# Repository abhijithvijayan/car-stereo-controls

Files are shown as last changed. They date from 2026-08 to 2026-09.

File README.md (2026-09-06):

# wireless-steering-wheel-controls

> ⚠️ Work in progress

Wireless steering-wheel audio controls for a car head unit.

The steering-wheel buttons can't be wired through to the dash, and the head unit
only accepts commands over its wired SWC (steering-wheel-control) resistor input.
So the link is split in two over BLE:

```
[steering wheel]                         [behind dash, car-powered]
 buttons → XIAO nRF52840  ──BLE──▶  ESP32-C3  ──resistor codes──▶  head unit SWC input
 (coin-cell powered)                (always on, scans)
```

## Subprojects

| Dir | Board | Role |
|-----|---|---|
| [`transmitter/`](transmitter/) | Seeed XIAO nRF52840 | On the wheel, battery powered. Reads the button cluster and broadcasts presses over connectionless BLE advertising. |
| [`receiver/`](receiver/) | ESP32-C3 | Behind the dash, always powered. Scans for the broadcasts and drives the head unit's SWC input. |

Each subproject is a self-contained PlatformIO project — open the subdirectory
(not this root) in your IDE, or build from inside it:

```bash
cd transmitter && pio run    # or: pio run -t upload
cd receiver     && pio run
```

## How it works

Signal path: button resistance → ADC voltage → BLE packet → mux channel
selection → resistance on the SWC wire → voltage read by the head unit.

### Transmitter (wheel side)

The wheel's 9 buttons form a resistor ladder on a single analog wire: each
button connects a different cumulative resistance (360 Ω–16.46 kΩ) to ground.
The XIAO idles in sleep (~20 µA) and wakes on a button press via a GPIO PORT
event. It then drives the ladder through a 5.1 k series resistor, samples the
node with the ADC (median of 3), and classifies the button by comparing the
resistance against a threshold table.

Button events are broadcast as connectionless BLE advertisements (no pairing,
no connection) carrying 7 bytes of manufacturer data:

```
[FF FF] [42]  [01]    [button] [event]              [seq]
company magic version 0-8      PRESS/HOLD/RELEASE   +1 per event
```

Repeatable buttons (VOL±/SRC±) re-send HOLD every 200 ms while held. Every
frame is re-broadcast unchanged until the next event, which serves as a
heartbeat. The chip returns to sleep 1 s after release.

### Receiver (dash side)

An ESP32-C3 scans passively at 100% duty cycle. The BLE callback filters on
company + magic + version, deduplicates by sequence number (each frame arrives
many times), and writes the newest event into a single-slot mailbox
(overwrite, not a FIFO: queued stale PRESS/RELEASE events would no longer
describe the current button state). A local rotary encoder (volume knob) is
decoded by a quadrature state machine; each detent enqueues one tap into a
ring buffer.

Both inputs are consumed by a single output state machine — the only code
that drives the output pins. A held wheel button is mirrored: its code is
asserted while the button is held, re-asserted only when the button changes,
and released on RELEASE or after 500 ms without a heartbeat (failsafe against
a dead transmitter). Encoder detents are counted and emitted as 50 ms press
pulses with 50 ms spacing between pulses.

### Output stage → head unit

Asserting a button: two 74HC4051 analog multiplexers (shared S0–S2 select
lines; per-mux active-low enables with 10 k pull-ups so both muxes are off
until the firmware initializes) connect one of nine fixed resistors between a
head-unit SWC wire and ground. Each mux common reaches its SWC wire through a
photoMOS solid-state relay (see [power-fail isolation](#power-fail-isolation)
below). Electrically this is identical to a wired OEM button press.

The head unit holds each SWC input at 3.335 V through an internal ~650 Ω
pull-up and reads the divider voltage produced by the pressed button's
resistance (V = 3.335 · (R + R_on) / (R + R_on + 650), with mux
R_on ≈ 130 Ω). In learning mode it stores one voltage per button and later
matches live readings within roughly ±50 mV.

Installed codes:

| Ref | Button | Mux/channel | Resistor | Wire voltage |
|-----|---|---|---|---|
| R1  | VOL_UP | M1 / Y0 | 100 Ω | 0.87 V |
| R2  | SRC_PUSH  | M1 / Y1 | 220 Ω | 1.16 V |
| R3  | SRC_UP | M1 / Y2 | 330 Ω | 1.38 V |
| R4  | SRC_DOWN  | M1 / Y3 | 470 Ω | 1.60 V |
| R7  | CALL_END  | M2 / Y2 | 680 Ω | 1.85 V |
| R8  | VOICE | M2 / Y1 | 1 k | 2.11 V |
| R5  | VOL_DOWN  | M1 / Y4 | 2 k | 2.55 V |
| R9  | ANSWER | M2 / Y0 | 3.3 k | 2.80 V |
| R6  | MUTE | M1 / Y5 | 6.8 k | 3.05 V |
| — | idle | — | open | 3.335 V |

(M1 common → SSR → SWC wire 1, M2 common → SSR → SWC wire 2, shared ground.
Support parts: R10/R11 = 10 k pull-ups on the mux enables, C1/C2 = 100 nF
decoupling at each mux VCC, U3/U5 = AQY212EH photoMOS relays with
R12/R13 = 680 Ω LED resistors.)

The nine values are chosen for voltage spacing on the head unit's divider —
minimum ~215 mV between any two codes on the combined axis (placed on the
rarely-used SRC pair), ≥ 245 mV around the volume/mute/call buttons, and the
set is collision-free even if the head unit compares both wires against one
learned list. They are unrelated to the wheel's own ladder values: a
resistance code is only meaningful relative to the pull-up that reads it, and
the two sides have different pull-ups (5.1 k vs ~650 Ω) — the wheel's
16.46 kΩ top value would compress to unusably small voltage steps on a 650 Ω
divider.

### Power-fail isolation

The receiver is powered from the head unit's own USB port, and the head unit
can be on while the receiver is dead — during engine cranking (the head unit
sheds its USB load for a few seconds) or with the cable unplugged. An
unpowered 74HC4051 is not an open circuit: like most CMOS parts it has ESD
protection diodes from every signal pin to VCC, so the head unit's 650 Ω
pull-up back-feeds through the mux common into the dead 3.3 V rail. The SWC
wires sag from 3.335 V to ~2.2 V — right at a learned code's window, with
others swept through on the way — so a dead receiver used to press phantom
buttons. No firmware can help, because none is running.

As defense in depth, the button assignment accounts for this: the ~2.1 V slot
nearest the back-feed voltage belongs to VOICE (a phantom there only pokes the
voice assistant), while the phone-critical ANSWER sits at 2.80 V, far from
every measured fault voltage.

The fix is a normally-open photoMOS relay (Panasonic AQY212EH) in series
between each mux common and its SWC wire. The relay's input side is an
internal infrared LED fed from the raw USB 5 V rail through 680 Ω (~5.5 mA,
inside the datasheet's recommended 5–10 mA band; still ≥4 mA above the 3 mA
guaranteed trigger at the worst-case corner of USB's 4.4 V floor, max LED Vf,
and resistor tolerance). The only coupling to the output MOSFETs is light:
when USB power dies the LED goes dark and the outputs become a genuinely open
circuit, so the wires float at the 3.335 V idle exactly as if nothing were
connected. The LED resistors tap the 5 V node ahead of the module's regulator
and bulk capacitance so the relays open before the 3.3 V rail can sag into
the back-feed region.

Cost of the extra series element: ~0.85 Ω on-resistance, which shifts the
most sensitive code (VOL_UP) by ~3 mV and the gaps between codes by even
less — re-running the head unit's learning mode after installation absorbs
it entirely.

## Third-party code & assets

Everything not listed below is original work under [MIT](LICENCE).

### Code

- `receiver/src/rotary_encoder.{h,cpp}` — quadrature state tables derived from
  [Ben Buxton's rotary library](https://github.com/buxtronix/arduino/tree/master/libraries/Rotary),
  Copyright 2011 Ben Buxton, **GPL v3**. These two files remain under GPL v3 (it
  cannot be relicensed to MIT); fine for private/personal use, but they carry
  GPL terms if this repo is ever distributed.

### Hardware / CAD

- `circuit/custom/Seeed_Studio_XIAO_Series.kicad_sym` and
  `circuit/custom/XIAO-nRF52840-DIP.kicad_mod` — KiCad schematic symbol and
  footprint from Seeed Studio's official
  [XIAO KiCad libraries](https://wiki.seeedstudio.com/XIAO_BLE/#seeed-studio-xiao-nrf52840)
  ([symbols](https://files.seeedstudio.com/wiki/XIAO-KiCad-Library/XIAO_Series_SCH_Symbols.zip),
  [footprints](https://files.seeedstudio.com/wiki/XIAO-KiCad-Library/New_XIAO_Series_Footprints.zip)),
  © Seeed Studio, [CC BY-SA 4.0](https://wiki.seeedstudio.com/License/)
  (Seeed wiki resources license). The footprint has local modifications;
  as CC BY-SA derivatives, these two files remain CC BY-SA 4.0.

- `circuit/custom/ESP32-C3_SUPERMINI_TH.kicad_sym`,
  `circuit/custom/MODULE_ESP32-C3_SUPERMINI_TH.kicad_mod`, and
  `circuit/custom/ESP32-C3_SUPERMINI_TH.step` — symbol, footprint, and 3D model
  from [SnapMagic Search (SnapEDA)](https://www.snapeda.com/parts/ESP32-C3%20SuperMini_TH/Espressif%20Systems/view-part/),
  [CC BY-SA 4.0 with Design Exception 1.0](https://support.snapeda.com/en/articles/2957814-what-is-the-license-for-symbols-and-footprints)
  (the exception lets designs and boards built with these files be licensed
  freely; the files themselves remain CC BY-SA with attribution).

- `circuit/custom/XIAO-nRF52840 v15.step` — 3D board model from the GrabCAD
  Community Library:
  [Seeed Studio XIAO nRF52840 (Sense)](https://grabcad.com/library/seeed-studio-xiao-nrf52840-sense-1).
  ⚠️ GrabCAD community models are licensed for **private use**; public
  redistribution requires the uploader's permission.

- `3d models/battery_case.FCStd` and `3d models/Battery Enclosure - cr2450.stl`
  — CR2450 battery holder: FreeCAD project created to modify, and the modified
  STL exported from, the
  [CRxxxx battery holder generator](https://cults3d.com/en/3d-model/tool/crxxxx-battery-holder-generator)
  output by **shusy** on Cults3D, **CC BY-NC** — both files remain CC BY-NC.
  `3d models/transmitter_case.FCStd` is original work but embeds the modified
  holder, so it is not usable commercially as a whole.

### Tools

Designed with [KiCad](https://www.kicad.org/) (PCB) and
[FreeCAD](https://www.freecad.org/) (enclosure); the PCB was brought into the
FreeCAD enclosure project with
[kicadStepUp](https://github.com/easyw/kicadStepUpMod/) (easyw, AGPL-3.0).
Firmware built with [PlatformIO](https://platformio.org/). Tool licenses do
not apply to this repo's content.

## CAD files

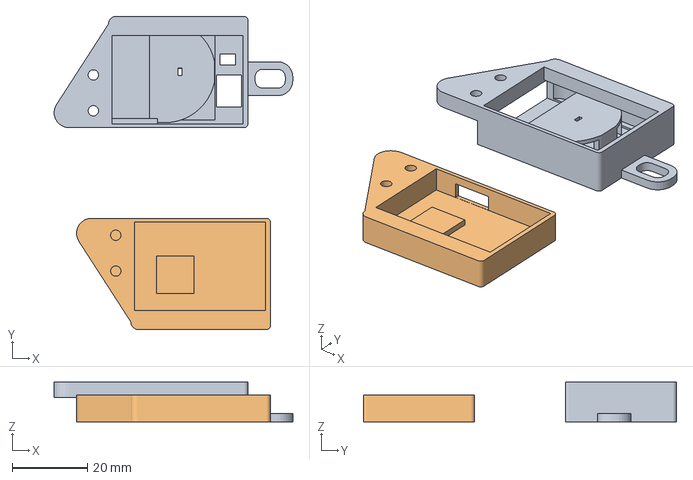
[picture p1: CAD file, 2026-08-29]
3d models/Transmitter Case - Slicer File.3mf
63.3 x 83.0 x 10.6 mm
Transmitter Case.stl x 2

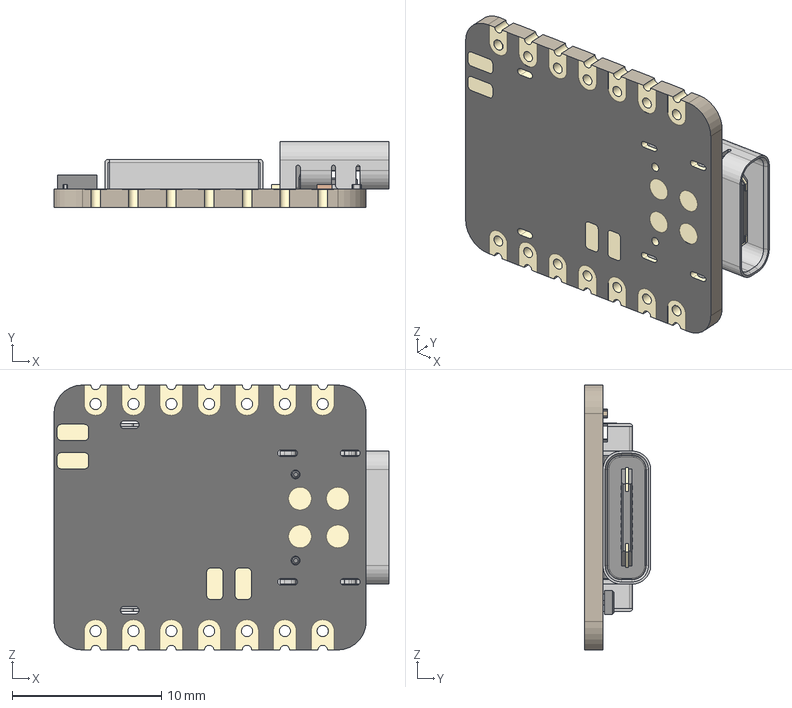
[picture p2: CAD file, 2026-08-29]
circuit/custom/XIAO-nRF52840 v15.step
22.5 x 4.46 x 17.8 mm
BOSS-EXTRUDE14_8_
BOSS-EXTRUDE7_4_
BOSS-EXTRUDE7_3_
BOSS-EXTRUDE14_4_
BOSS-EXTRUDE14_2_
BOSS-EXTRUDE14_11_
BOSS-EXTRUDE7_7_
BOSS-EXTRUDE14_9_
BOSS-EXTRUDE14_3_
BOSS-EXTRUDE14_7_
MIRROR2
BOSS-EXTRUDE14_5_
BOSS-EXTRUDE14_12_
BOSS-EXTRUDE7_8_
BOSS-EXTRUDE7_1_
BOSS-EXTRUDE14_10_
BOSS-EXTRUDE7_9_
BOSS-EXTRUDE14_6_
BOSS-EXTRUDE14_1_
BOSS-EXTRUDE7_6_
BOSS-EXTRUDE7_2_
CUT-EXTRUDE5
BOSS-EXTRUDE7_5_
Shield
Pins
CAP x 2
ANT1
Silkscreen
CAP 3
LED
USR
2 v1

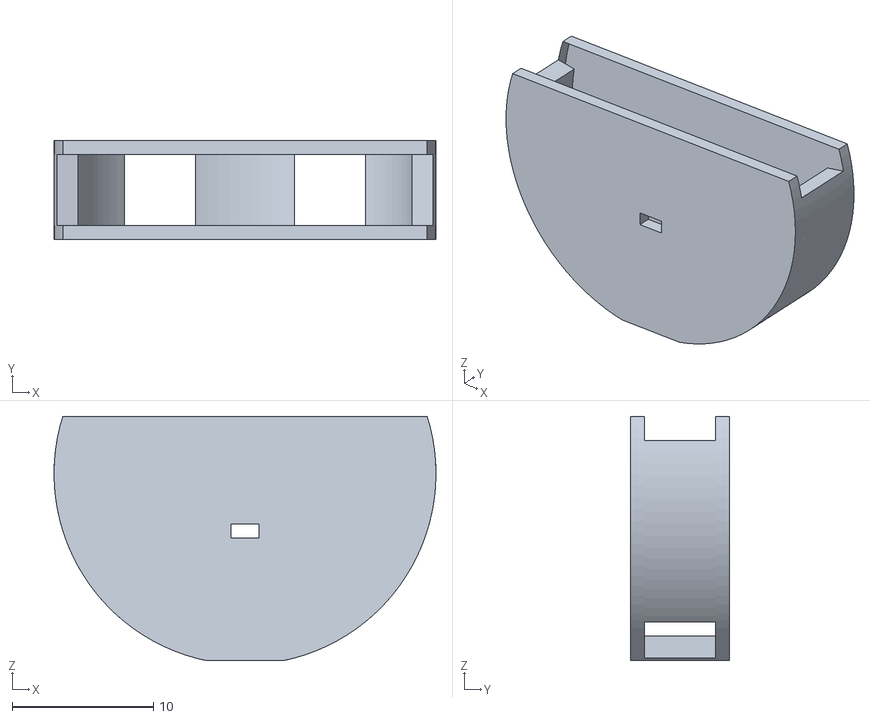
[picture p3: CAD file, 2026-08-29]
3d models/Battery Enclosure - cr2450.stl
27.0 x 7.00 x 17.3

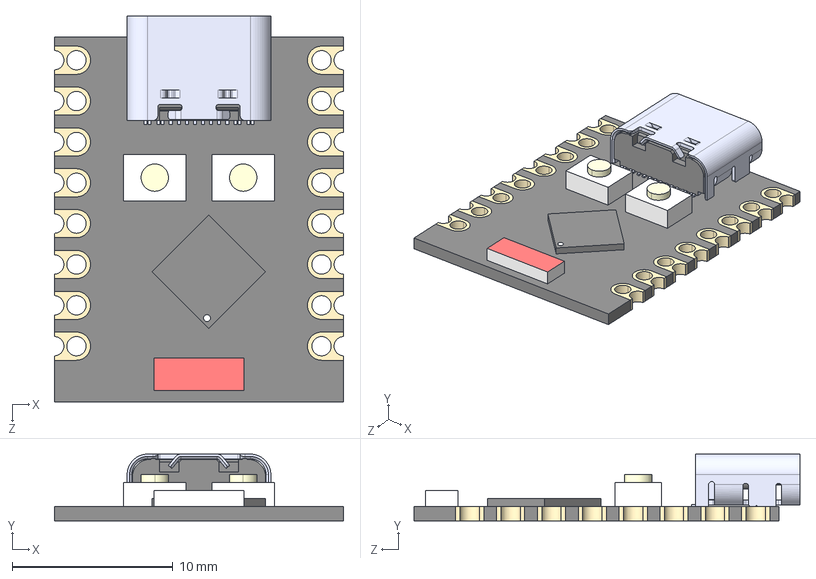
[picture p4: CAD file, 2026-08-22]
circuit/custom/ESP32-C3_SUPERMINI_TH.step
18.0 x 4.16 x 24.0 mm
Board c3mini
USB C
components (other)^ESP32-C3 SuperMini

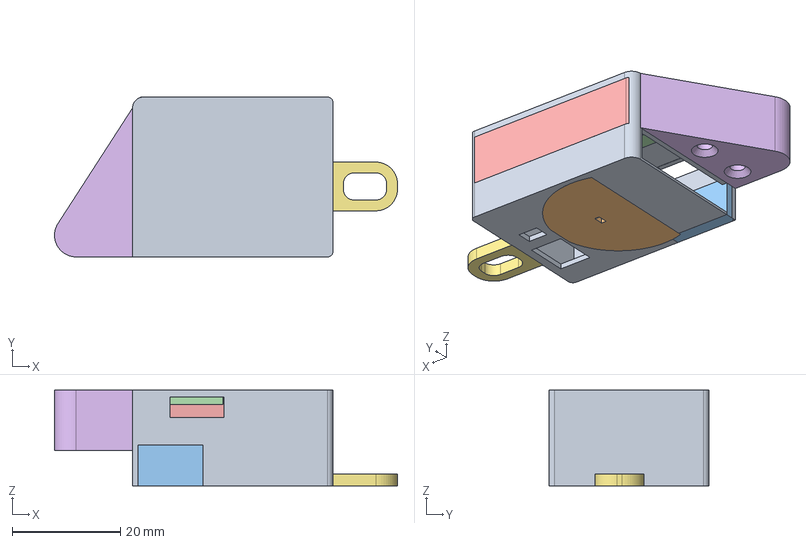
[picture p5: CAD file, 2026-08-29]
3d models/transmitter_case.FCStd
63.3 x 29.5 x 17.7 mm
Case
Battery Case
Lift 1
Support Top
Backsupport
Top support
Screw Clip

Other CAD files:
3d models/battery_case.FCStd
3d models/Transmitter Case.stl

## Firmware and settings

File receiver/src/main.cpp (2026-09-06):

/*
 *  Dash unit — ESP32-C3 BLE scanner + SWC output stage.
 */

// Framework headers aren't -Wconversion clean; silence their warnings so the flag
// (build_src_flags in platformio.ini) only polices our own code below.
#pragma GCC diagnostic push                         // save current warning settings
#pragma GCC diagnostic ignored "-Wconversion"       // turn THIS warning off
#pragma GCC diagnostic ignored "-Wsign-conversion"  // turn THIS warning off
#include <Arduino.h>                                // code compiled here uses the relaxed setting
#include <NimBLEDevice.h>
#pragma GCC diagnostic pop                          // restore what was saved at step 1

#include <swc_protocol.h>
#include <rotary_encoder.h>

using namespace swc;

// cooperative yield per loop pass (keeps BLE/idle/watchdog alive)
constexpr uint32_t LOOP_YIELD_MS = 5;

constexpr uint32_t HEARTBEAT_TIMEOUT_MS = 500;

constexpr uint8_t PIN_MUX_S0 = 0;
constexpr uint8_t PIN_MUX_S1 = 1;
constexpr uint8_t PIN_MUX_S2 = 3;
constexpr uint8_t PIN_MUX_1_ENABLE = 4;
constexpr uint8_t PIN_MUX_2_ENABLE = 5;

constexpr uint8_t PIN_ENCODER_A = 9;
constexpr uint8_t PIN_ENCODER_B = 8;
constexpr uint8_t PIN_ENCODER_PUSH = 10;

// push contact must be edge-free this long before a press-down edge counts
constexpr uint32_t PUSH_QUIET_MS = 30;

RotaryEncoder encoder(PIN_ENCODER_A, PIN_ENCODER_B, EncoderStepMode::FULL_STEP);

volatile uint8_t pendingWheelButton = BUTTON_NONE;
volatile uint8_t pendingWheelEvent = RELEASE;
volatile bool hasPendingWheelEvent = false;
volatile uint32_t lastWheelHeardAt = 0; // heartbeat for the timeout failsafe

enum OutputState : uint8_t {
    OUTPUT_IDLE,
    OUTPUT_ACTIVE
};

OutputState outputState = OUTPUT_IDLE;
uint8_t currentActiveButton = BUTTON_NONE;

class BLEScanCallback : public NimBLEScanCallbacks {
    public: void onResult(const NimBLEAdvertisedDevice *device) override {
        const std::string manufacturerData = device->getManufacturerData();
        if (manufacturerData.length() != PACKET_LENGTH) {
            return;
        }

        const auto *packet = reinterpret_cast<const uint8_t *>(manufacturerData.data());
        if (packet[0] != COMPANY_ID_LO || packet[1] != COMPANY_ID_HI || packet[2] != MAGIC || packet[3] != VERSION) {
            return;
        }

        const uint32_t now = millis();
        const uint32_t sinceLast = now - lastWheelHeardAt;
        lastWheelHeardAt = now;

        const uint8_t button = packet[PacketIndex::BUTTON_DATA];
        const uint8_t event = packet[PacketIndex::EVENT_DATA];
        const uint8_t sequence = packet[PacketIndex::SEQUENCE_NUMBER];

        static bool initialized = false;
        // The wheel re-broadcasts the same frame until the next event; act once per sequence.
        static uint8_t lastSequence = 0;
        const bool isNewSession = !initialized || sinceLast > HEARTBEAT_TIMEOUT_MS;
        if (!isNewSession && sequence == lastSequence) {
            return;
        }

        initialized = true;
        lastSequence = sequence;

        pendingWheelButton = button;
        pendingWheelEvent = event;
        hasPendingWheelEvent = true;

        #ifdef DEBUG_BUILD
            const char *eventName =
                event == PRESS   ? "PRESS"   :
                event == HOLD    ? "HOLD"    :
                event == RELEASE ? "RELEASE" :
                event == FAULT   ? "FAULT"   : "?";
            const uint8_t batteryByte = packet[PacketIndex::BATTERY_LEVEL];
            if (batteryByte == BATTERY_NOT_SAMPLED) {
                Serial.printf("[%s] RSSI %d button=%u event=%s seq=%u batt=n/a\n", device->getAddress().toString().c_str(), device->getRSSI(), button, eventName, sequence);
            } else {
                Serial.printf("[%s] RSSI %d button=%u event=%s seq=%u batt=%umV\n", device->getAddress().toString().c_str(), device->getRSSI(), button, eventName, sequence,
                              static_cast<unsigned>(batteryByte) * BATTERY_UNIT_MILLIVOLTS);
            }
        #endif
    }
};

void setAddress(const uint8_t channel) {
    digitalWrite(PIN_MUX_S0, (channel & 0x01u) ? HIGH : LOW);
    digitalWrite(PIN_MUX_S1, (channel & 0x02u) ? HIGH : LOW);
    digitalWrite(PIN_MUX_S2, (channel & 0x04u) ? HIGH : LOW);
}

void releaseCodes() { // Ē active-low → HIGH = off
    digitalWrite(PIN_MUX_1_ENABLE, HIGH);
    digitalWrite(PIN_MUX_2_ENABLE, HIGH);
}

void activateKeyCode(const uint8_t button) {
    const OutputCode &code = OUTPUT_CODES[button];
    releaseCodes();
    setAddress(code.channel);
    digitalWrite(code.mux == MUX_1 ? PIN_MUX_1_ENABLE : PIN_MUX_2_ENABLE, LOW);
}

void setup() {
    // The 74HC4051's enable pin is Ē — active-low (the bar over the E means "true when low")
    // Ē = LOW → mux is on, Ē = HIGH → mux is off
    // pinMode MUST come first: this core discards digitalWrite() on an unconfigured pin,
    // so a preceding write would be a no-op and the pin would come up driving LOW.
    // R10/R11 hold Ē high until here; the µs LOW blip between the two calls is far
    // below what the stereo's SWC sensing can register.
    pinMode(PIN_MUX_1_ENABLE, OUTPUT);
    digitalWrite(PIN_MUX_1_ENABLE, HIGH);

    pinMode(PIN_MUX_2_ENABLE, OUTPUT);
    digitalWrite(PIN_MUX_2_ENABLE, HIGH);

    pinMode(PIN_MUX_S0, OUTPUT);
    digitalWrite(PIN_MUX_S0, LOW);
    pinMode(PIN_MUX_S1, OUTPUT);
    digitalWrite(PIN_MUX_S1, LOW);
    pinMode(PIN_MUX_S2, OUTPUT);
    digitalWrite(PIN_MUX_S2, LOW);

    // the encoder's common pin is wired to GND, so its contacts pull lines down; the internal ~45 k pull-ups give the idle-HIGH level
    encoder.begin();
    pinMode(PIN_ENCODER_PUSH, INPUT_PULLUP);

    #ifdef DEBUG_BUILD
        Serial.begin(115200);
    #endif

    NimBLEDevice::init("");
    NimBLEScan *scan = NimBLEDevice::getScan();
    scan->setScanCallbacks(new BLEScanCallback());
    scan->setActiveScan(false); // We only get advertisements passively
    scan->setInterval(100); // 100ms scan cycle
    scan->setWindow(100); // window == interval -> radio listening 100% of the time
    scan->setDuplicateFilter(false); // deliver EVERY advertisement, even from known devices
    scan->start(0, false); // 0 = scan forever
}

constexpr uint8_t TAP_QUEUE_SIZE = 10;
constexpr uint32_t TAP_HOLD_MS = 50;
constexpr uint32_t TAP_SPACING_MS = 50;

uint8_t tapQueue[TAP_QUEUE_SIZE];

uint8_t tapHead = 0;
uint8_t tapCount = 0;

void enqueueTap(const uint8_t button) {
    if (tapCount >= TAP_QUEUE_SIZE) {
        #ifdef DEBUG_BUILD
            Serial.printf("[queue] FULL — dropped %s\n", OUTPUT_CODES[button].name);
        #endif

        return;
    }

    tapQueue[(tapHead + tapCount) % TAP_QUEUE_SIZE] = button;
    tapCount += 1;

    #ifdef DEBUG_BUILD
        Serial.printf("[queue] +%s (depth %u)\n", OUTPUT_CODES[button].name, tapCount);
    #endif
}

void pollEncoder(const uint32_t now) {
    const int8_t step = encoder.sampleStep();
    if (step > 0) {
        enqueueTap(VOL_UP);
    } else if (step < 0) {
        enqueueTap(VOL_DOWN);
    }

    static bool previous = digitalRead(PIN_ENCODER_PUSH) == LOW; // poll first on boot to get the actual state in case user is pressing on boot
    static uint32_t lastPressAt = 0;

    const bool current = digitalRead(PIN_ENCODER_PUSH) == LOW;  // pull-up: LOW = pressed
    if (current != previous) {
        // mute if the line was quiet beforehand
        const bool quietLongEnough = now - lastPressAt >= PUSH_QUIET_MS;
        if (current && quietLongEnough) {
            enqueueTap(MUTE);
        }

        #ifdef DEBUG_BUILD
            if (current && !quietLongEnough) {
                Serial.printf("[enc] push down-edge rejected — line moved %ums ago\n", now - lastPressAt);
            }
        #endif

        previous = current;
        lastPressAt = now;
    }
}

void processButtonsPress(const uint32_t now) {
    switch (outputState) {
        case OUTPUT_IDLE: {
            if (hasPendingWheelEvent) {
                hasPendingWheelEvent = false;

                // Take a snapshot to prevent volatile data getting overwritten by the NimBLE task mid processing
                const uint8_t nextButton = pendingWheelButton;
                const uint8_t nextEvent = pendingWheelEvent;

                if ((nextEvent == PRESS || nextEvent == HOLD) && nextButton < BUTTON_COUNT) {
                    activateKeyCode(nextButton);
                    currentActiveButton = nextButton;
                    outputState = OUTPUT_ACTIVE;

                    #ifdef DEBUG_BUILD
                        Serial.printf("[mux] assert %s\n", OUTPUT_CODES[nextButton].name);
                    #endif
                }
            }

            break;
        }

        case OUTPUT_ACTIVE: {
            if (hasPendingWheelEvent) {
                hasPendingWheelEvent = false;

                // Take a snapshot to prevent volatile data getting overwritten by the NimBLE task mid processing
                const uint8_t nextButton = pendingWheelButton;
                const uint8_t nextEvent = pendingWheelEvent;

                if (nextEvent == RELEASE || nextEvent == FAULT || nextButton >= BUTTON_COUNT) {
                    releaseCodes();
                    currentActiveButton = BUTTON_NONE;
                    outputState = OUTPUT_IDLE;

                    #ifdef DEBUG_BUILD
                        Serial.printf("[mux] release (%s)\n", nextEvent == FAULT ? "wheel FAULT" : "wheel RELEASE");
                    #endif
                } else if (nextButton != currentActiveButton) {
                    activateKeyCode(nextButton);
                    currentActiveButton = nextButton;

                    #ifdef DEBUG_BUILD
                        Serial.printf("[mux] switch to %s\n", OUTPUT_CODES[nextButton].name);
                    #endif
                }
            } else if (now - lastWheelHeardAt > HEARTBEAT_TIMEOUT_MS) {
                releaseCodes();
                currentActiveButton = BUTTON_NONE;
                outputState = OUTPUT_IDLE;

                #ifdef DEBUG_BUILD
                    Serial.printf("[mux] release (heartbeat TIMEOUT after %ums)\n", HEARTBEAT_TIMEOUT_MS);
                #endif
            }

            break;
        }

        default: {
            break;
        }
    }
}

void loop() {
    const uint32_t now = millis();

    processButtonsPress(now);
    pollEncoder(now);
    delay(LOOP_YIELD_MS); // yield to the BLE + idle tasks (single core)
}

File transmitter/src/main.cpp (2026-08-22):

/*
 *  Wheel unit — XIAO nRF52840 BLE broadcaster.
 */

// Framework headers aren't -Wconversion clean; silence their warnings so the flag
// (build_src_flags in platformio.ini) only polices our own code below.
#pragma GCC diagnostic push                         // save current warning settings
#pragma GCC diagnostic ignored "-Wconversion"       // turn THIS warning off
#pragma GCC diagnostic ignored "-Wsign-conversion"  // turn THIS warning off
#include <Arduino.h>                                // code compiled here uses the relaxed setting
#include <Adafruit_TinyUSB.h>
#include <Adafruit_SPIFlash.h>
#include <bluefruit.h>
#pragma GCC diagnostic pop                          // restore what was saved at step 1

#include <swc_protocol.h>
#include "wake_on_press.h"

using namespace swc;

// Auto-repeat interval for held VOL±/SRC± buttons
constexpr uint32_t HOLD_REPEAT_INTERVAL = 200;

// Idle time since the last broadcast before suspending cpu
constexpr uint32_t IDLE_BEFORE_SLEEP = 1000;

uint8_t bleManufacturerData[PACKET_LENGTH] =
    {
    COMPANY_ID_LO, COMPANY_ID_HI, // company ID 0xFFFF (little-endian)
    MAGIC,
    VERSION,
    BUTTON_NONE, // button code: 0-8, or 0xFF = idle/none
    ButtonEvent::RELEASE, // event: start in the released/idle state
    0x00, // sequence: +1 on every broadcast, for receiver dedupe
    BATTERY_NOT_SAMPLED, // battery: cell voltage in 20mV units, refreshed at boot and on each wake
};

constexpr int PIN_DRIVE = D1;
constexpr int PIN_SENSE = A0; // on the XIAO nRF52840, D0 and A0 are literally the same physical pin
constexpr float DIVIDE_NETWORK_RESISTOR_VALUE = 5100.0; // 5.1K ohm (R2)
constexpr uint32_t NODE_FILTER_CAPACITOR_NANOFARADS = 10; // 10 nF (C1)

// The node settles exponentially through R2 into C1 (τ = R2 × C1) once D1 starts
// driving. Wait 6τ before reading: residual error e⁻⁶ ≈ 0.25% ≈ 10 ADC counts, well below the band spacing.
// Ω × nF / 1000 = µs
constexpr uint32_t NODE_SETTLE_MICROS =
    (6u * static_cast<uint32_t>(DIVIDE_NETWORK_RESISTOR_VALUE) * NODE_FILTER_CAPACITOR_NANOFARADS + 999u) / 1000u;

/**
 *  When button is pressed and drive D1 HIGH, the node sits in a voltage divider:
 *
*  D1 (VDD) ──[ 5100 Ω ]──┬── node (A0 reads here)
*                         │
*                      [ r Ω ]   (the pressed button)
*                         │
*                        GND
*
*  Voltage-divider rule: the lower resistor gets a share of the supply equal to its fraction of the total resistance
*
*  V_node = VDD × r / (r + 5100)
*  Now convert volts to ADC counts. The ADC gives counts = 4095 × (V_node / V_ref), and because we chose AR_VDD4, V_ref = VDD:
*  counts = 4095 × V_node / VDD = 4095 × [VDD × r/(r+5100)] / VDD = 4095 × r / (r + 5100)
 */
uint16_t resistanceToCounts(const float resistance) {
    return static_cast<uint16_t>(lroundf(4095.0f * resistance / (resistance + DIVIDE_NETWORK_RESISTOR_VALUE)));
}

uint16_t buttonThresholds[BUTTON_COUNT];

/**
 *  Compute the midpoint between this button and the next
 *
 *  Note: 4095 (idle/open is the next "level" above CALL_END)
 */
void computeButtonThresholds() {
    uint16_t counts[BUTTON_COUNT];
    for (int index = 0; index < BUTTON_COUNT; index += 1) {
        counts[index] = resistanceToCounts(BUTTONS[index].resistance);
    }

    for (int index = 0; index < BUTTON_COUNT; index += 1) {
        if (index == BUTTON_COUNT - 1) {
            constexpr int idle = 4095;
            buttonThresholds[index] = static_cast<uint16_t>((counts[index] + idle) / 2);
        } else {
            buttonThresholds[index] = static_cast<uint16_t>((counts[index] + counts[index + 1]) / 2);
        }
    }
}

int identifyButton(const uint16_t readCount) {
    if (readCount < (resistanceToCounts(BUTTONS[0].resistance) / 2)) {
        return -2; // Fault / Short
    }

    // Find the band the value falls in
    for (int index = 0; index < BUTTON_COUNT; index += 1) {
        if (readCount < buttonThresholds[index]) {
            return index;
        }
    }

    return -1; // IDLE
}

uint16_t sampleNode() {
    pinMode(PIN_DRIVE, OUTPUT);
    digitalWrite(PIN_DRIVE, HIGH);
    delayMicroseconds(NODE_SETTLE_MICROS);

    const auto first = static_cast<uint16_t>(analogRead(PIN_SENSE));
    const auto second = static_cast<uint16_t>(analogRead(PIN_SENSE));
    const auto third = static_cast<uint16_t>(analogRead(PIN_SENSE));

    // We need to take median of the readings to avoid any spikes polluting the output if we were to do average
    // median = a + b + c − max(a,b,c) − min(a,b,c)

    pinMode(PIN_DRIVE, INPUT); // release the pin

    return static_cast<uint16_t>(first + second + third - max(first, max(second, third)) - min(first, min(second, third)));
}

void configureAdvertising() {
    #ifdef DEBUG_BUILD
        Bluefruit.setName("SWC");
    #endif

    // Non-connectable, non-scannable: transmit and sleep between intervals — no RX window.
    Bluefruit.Advertising.setType(BLE_GAP_ADV_TYPE_NONCONNECTABLE_NONSCANNABLE_UNDIRECTED);
    Bluefruit.Advertising.addFlags(BLE_GAP_ADV_FLAGS_LE_ONLY_GENERAL_DISC_MODE);

    #ifdef DEBUG_BUILD
        Bluefruit.Advertising.addName();
    #endif

    Bluefruit.Advertising.addManufacturerData(bleManufacturerData, sizeof(bleManufacturerData));
}

// Cell voltage in BATTERY_UNIT_MILLIVOLTS units. The battery IS VDD (cell feeds
// the 3V3 pin directly), so the chip measures its own supply. The ratiometric AR_VDD4
// used for button sampling would read VDD-vs-VDD = full scale always, so the reading
// swaps to the internal 0.6V reference (AR_INTERNAL, 3.6V full scale) and back.
uint8_t batteryLevel = BATTERY_NOT_SAMPLED;

void sampleBatteryLevel() {
    analogReference(AR_INTERNAL); // 0.6V reference, 1/6 gain: full scale = 3.6V
    const uint32_t counts = analogReadVDD();
    analogReference(AR_VDD4); // restore the ratiometric button reference
    const uint32_t millivolts = counts * 3600u / 4095u;
    batteryLevel = static_cast<uint8_t>(millivolts / BATTERY_UNIT_MILLIVOLTS);
}

uint32_t lastBroadcastAt = 0;

// Publish a new event to the live advert. We can't just mutate the buffer — Bluefruit copies
// it, and the SoftDevice won't reconfigure a running advert — so stop -> clear -> rebuild ->
// start. Bumping seq is what lets the receiver tell a fresh event from a re-broadcast.
void broadcastEvent(const uint8_t button, const ButtonEvent event) {
    bleManufacturerData[PacketIndex::BUTTON_DATA] = button;
    bleManufacturerData[PacketIndex::EVENT_DATA] = static_cast<uint8_t>(event);
    bleManufacturerData[PacketIndex::SEQUENCE_NUMBER]++; // intentional 255 -> 0 wrap
    bleManufacturerData[PacketIndex::BATTERY_LEVEL] = batteryLevel;

    Bluefruit.Advertising.stop();
    Bluefruit.Advertising.clearData();
    configureAdvertising();
    Bluefruit.Advertising.start(0); // Advertise forever

    lastBroadcastAt = millis();
}
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

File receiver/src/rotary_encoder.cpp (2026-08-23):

// Quadrature state machine and transition tables derived from Ben Buxton's
// Rotary library (github.com/buxtronix/arduino), Copyright 2011 Ben Buxton, GPL v3.
// This file remains under GPL v3 — see README.

#pragma GCC diagnostic push
#pragma GCC diagnostic ignored "-Wconversion"
#pragma GCC diagnostic ignored "-Wsign-conversion"
#include <Arduino.h>
#pragma GCC diagnostic pop

#include "rotary_encoder.h"

// Emit flags carried in the state byte's high bits; low nibble is the table row.
constexpr uint8_t EMIT_CW = 0x10;
constexpr uint8_t EMIT_CCW = 0x20;
constexpr uint8_t EMIT_MASK = 0x30;
constexpr uint8_t ROW_MASK = 0x0F;

// Each row is a state; each column is the next (A,B) reading as an index
// (00, 01, 10, 11); the entry is the state to move to, optionally OR'd with an
// emit flag. Only the exact Gray sequence reaches an emitting entry; any invalid
// jump falls back to START, so bounce and EMI walk harmlessly between sub-states.

namespace fullstep {
    // Rest (and emit) at AB = 11: START ─01→ CW_BEGIN ─00→ CW_NEXT ─10→ CW_FINAL ─11→ START+emit
    constexpr uint8_t START = 0x0;
    constexpr uint8_t CW_FINAL = 0x1;
    constexpr uint8_t CW_BEGIN = 0x2;
    constexpr uint8_t CW_NEXT = 0x3;
    constexpr uint8_t CCW_BEGIN = 0x4;
    constexpr uint8_t CCW_FINAL = 0x5;
    constexpr uint8_t CCW_NEXT = 0x6;

    constexpr uint8_t TRANSITIONS[7][4] = {
        // 00            01          10          11
        {START,        CW_BEGIN,   CCW_BEGIN,  START},            // START
        {CW_NEXT,      START,      CW_FINAL,   START | EMIT_CW},  // CW_FINAL
        {CW_NEXT,      CW_BEGIN,   START,      START},            // CW_BEGIN
        {CW_NEXT,      CW_BEGIN,   CW_FINAL,   START},            // CW_NEXT
        {CCW_NEXT,     START,      CCW_BEGIN,  START},            // CCW_BEGIN
        {CCW_NEXT,     CCW_FINAL,  START,      START | EMIT_CCW}, // CCW_FINAL
        {CCW_NEXT,     CCW_FINAL,  CCW_BEGIN,  START},            // CCW_NEXT
    };
}

namespace halfstep {
    // Rest (and emit) at both AB = 11 and AB = 00. Suffix = which rest the
    // motion departed from: CW from 11 goes 11→01→00 (emit), CW from 00 goes
    // 00→10→11 (emit).
    constexpr uint8_t START_11 = 0x0;      // the 11 rest (row 0, like fullstep::START)
    constexpr uint8_t CCW_BEGIN_11 = 0x1;
    constexpr uint8_t CW_BEGIN_11 = 0x2;
    constexpr uint8_t START_00 = 0x3;      // the 00 rest
    constexpr uint8_t CW_BEGIN_00 = 0x4;
    constexpr uint8_t CCW_BEGIN_00 = 0x5;

    constexpr uint8_t TRANSITIONS[6][4] = {
        // 00                      01             10             11
        {START_00,               CW_BEGIN_11,   CCW_BEGIN_11,  START_11},            // START_11
        {START_00 | EMIT_CCW,    START_11,      CCW_BEGIN_11,  START_11},            // CCW_BEGIN_11
        {START_00 | EMIT_CW,     CW_BEGIN_11,   START_11,      START_11},            // CW_BEGIN_11
        {START_00,               CCW_BEGIN_00,  CW_BEGIN_00,   START_11},            // START_00
        {START_00,               START_00,      CW_BEGIN_00,   START_11 | EMIT_CW},  // CW_BEGIN_00
        {START_00,               CCW_BEGIN_00,  START_00,      START_11 | EMIT_CCW}, // CCW_BEGIN_00
    };
}

void RotaryEncoder::begin() {
    pinMode(pinA, INPUT_PULLUP);
    pinMode(pinB, INPUT_PULLUP);
    tableState = fullstep::START; // 0x0 in both tables; self-syncs from any shaft position
}

uint8_t RotaryEncoder::samplePins() const {
    const uint8_t a = digitalRead(pinA) == HIGH ? 1u : 0u;
    const uint8_t b = digitalRead(pinB) == HIGH ? 1u : 0u;
    return static_cast<uint8_t>((a << 1u) | b);
}

int8_t RotaryEncoder::sampleStep() {
    const uint8_t (*transitions)[4] = stepMode == EncoderStepMode::FULL_STEP
        ? fullstep::TRANSITIONS
        : halfstep::TRANSITIONS;

    tableState = transitions[tableState & ROW_MASK][samplePins()];

    const uint8_t emit = tableState & EMIT_MASK;
    if (emit == EMIT_CW) {
        return 1;
    }

    if (emit == EMIT_CCW) {
        return -1;
    }

    return 0;
}

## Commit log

2026-08-22 feat: initial commit
    [.kicad_sch, ESP32-C3_SUPERMINI_TH.step, emitter.kicad_pcb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]
2026-08-22 feat: battery reading and fault handling
2026-08-23 feat: patch rotary encoder library from https://github.com/buxtronix/arduino/tree/master/libraries/Rotary
2026-08-23 refactor: update the new resistor values for the receiver
2026-08-29 feat: 3D cases models
    [Transmitter Case.stl, battery_case.FCStd, transmitter_case.FCStd]
2026-08-29 refactor: add labels to circuits
    [emitter.kicad_pcb, emitter.kicad_sch, receiver.kicad_pcb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]
2026-08-29 chore: add 3D files
    [Battery Enclosure - cr2450.stl, Transmitter Case - Slicer File.3mf, XIAO-nRF52840 v15.step]
2026-08-29 refactor: rename kicad project
    [transmitter.kicad_pcb, transmitter.kicad_sch]
2026-08-29 refactor: drop old Kicad project
    [.kicad_sch, emitter.kicad_pcb, emitter.kicad_sch]
2026-08-29 fix: KiCad assets directory links
    [receiver.kicad_pcb, transmitter.kicad_pcb]
2026-09-05 fix: update circuit
    [receiver.kicad_pcb]
2026-09-06 refactor: adjust resistors mapping to different buttons
